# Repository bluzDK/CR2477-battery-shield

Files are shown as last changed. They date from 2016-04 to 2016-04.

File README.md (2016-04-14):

<p align="center" >
Bluz
</p>

Bluz CR2477 Battery Shield Hardware Files
==========
Bluz is a Development Kit (DK) that implements the Wiring language and talks to the [Particle](https://www.particle.io/) cloud through Bluetooth Low Energy. It can be accessed through a REST API and programmed from a Web IDE.

The CR2477 battery shield is intended to let bluz run off the biggest, baddest coin cell battery in the land.

This shield is not produced or sold, the files are provided here as a reference or so others can create the shield themselves. The PCB can be purchased from [OSH Park directly here](https://oshpark.com/shared_projects/7VCoguxF). The BOM has all the parts listed with links to DigiKey for easy purchase. 

These files have been made available online through a [Creative Commons Attribution-ShareAlike 3.0](http://creativecommons.org/licenses/by-sa/3.0/) license.

You are welcome to distribute, remix, and use these files for commercial purposes. If you do so, please attribute the original design to Bluz both on the website and on the physical packaging of the product or in the instruction manual. All derivative works must be published under the same or a similar license.

All items are subject to change over time as the product is designed, so make sure you are always looking at the latest information by pulling often.

##Sections
<b>BOM</b>: Current Bill of Materials for the battery shield.

<b>HW Design</b>: Schematics, board layouts, and other design files.

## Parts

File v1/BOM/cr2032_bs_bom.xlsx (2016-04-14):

Part(s) | Package | Value | Description | Qty | Manufacturer | Mfg. Part Number | DigiKey Page | Data Sheet | Notes
Q1 | SOT323 |  | P-Channel MOSFET for reverse polarity protection | 1 | On | NTS2101PT1G | purchase (http://www.digikey.com/product-detail/en/on-semiconductor/NTS2101PT1G/NTS2101PT1GOSCT-ND/687135) | data (http://www.onsemi.com/pub_link/Collateral/NTS2101P-D.PDF)
S1 | Thru |  | DPDT Power Switch | 1 | E-Switch | EG1270 | purchase (http://www.digikey.com/product-detail/en/e-switch/EG1270/EG1847-ND/6076) | data (https://www.e-switch.com/system/asset/product_line/data_sheet/119/EG.pdf)
S2 | SMD |  | Jumper for LED | 1 | Copal | CHS-01TA | purchase (http://www.digikey.com/product-detail/en/copal-electronics-inc/CHS-01TA/563-1003-1-ND/948404) | data (http://www.nidec-copal-electronics.com/e/catalog/switch/chs.pdf)
C1 | 0603 | 0.1uF | 0603 Package | 1 |  | GRM188R71C104KA01D | purchase (http://www.digikey.com/product-detail/en/murata-electronics-north-america/GRM188R71C104KA01D/490-1532-1-ND/587771) | data (http://search.murata.co.jp/Ceramy/image/img/A01X/partnumbering_e_01.pdf)
L1 | 0603 |  | White SMD LED | 1 |  | LW Q38G-Q1S1-3K6L-1 | purchase (http://www.digikey.com/product-detail/en/osram-opto-semiconductors-inc/LW%20Q38G-Q1OO-3K6L-1/475-2832-1-ND/2176370) | data (http://www.osram-os.com/Graphics/XPic6/00086183_0.pdf)
R1 | 0603 | 1k Ohm | 1k Ohm | 1 |  | CRCW06031K00FKEA | purchase (http://www.digikey.com/product-detail/en/vishay-dale/CRCW06031K00FKEA/541-1.00KHCT-ND/1179809) | data (http://www.vishay.com/docs/20035/dcrcwe3.pdf)
BAT1 | SMD | 24mm | Battery holder for CR2477 | 1 | Keystone | 3039 | purchase (http://www.digikey.com/product-detail/en/keystone-electronics/3039/36-3039-ND/3884009) | data (http://keyelco.com/userAssets/file/M65p9.pdf)
JP2, JP3 | Thru |  | 0.1" 12-pin female header | 2 |  | PPTC121LFBN-RC | purchase (http://www.digikey.com/product-detail/en/sullins-connector-solutions/PPTC121LFBN-RC/S6100-ND/807231) | data (http://www.sullinscorp.com/drawings/78_P(N)PxCxxxLFBN-RC,_10492-H.pdf)

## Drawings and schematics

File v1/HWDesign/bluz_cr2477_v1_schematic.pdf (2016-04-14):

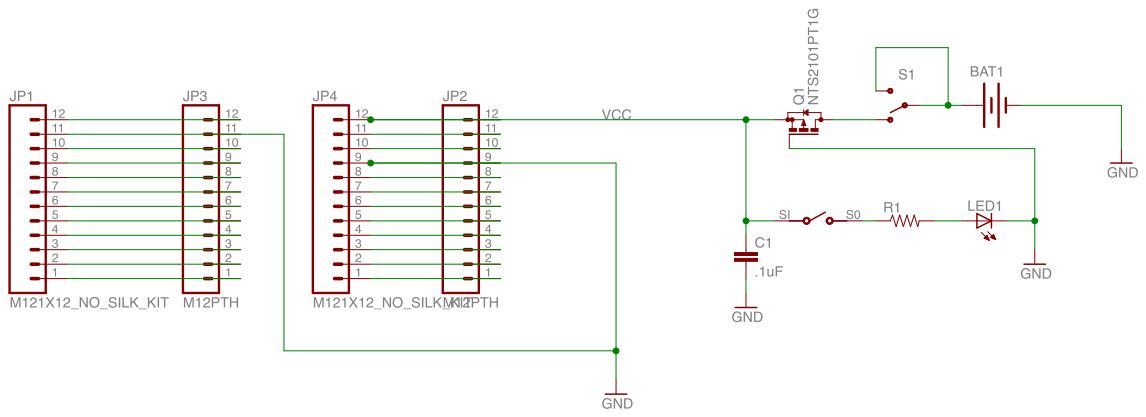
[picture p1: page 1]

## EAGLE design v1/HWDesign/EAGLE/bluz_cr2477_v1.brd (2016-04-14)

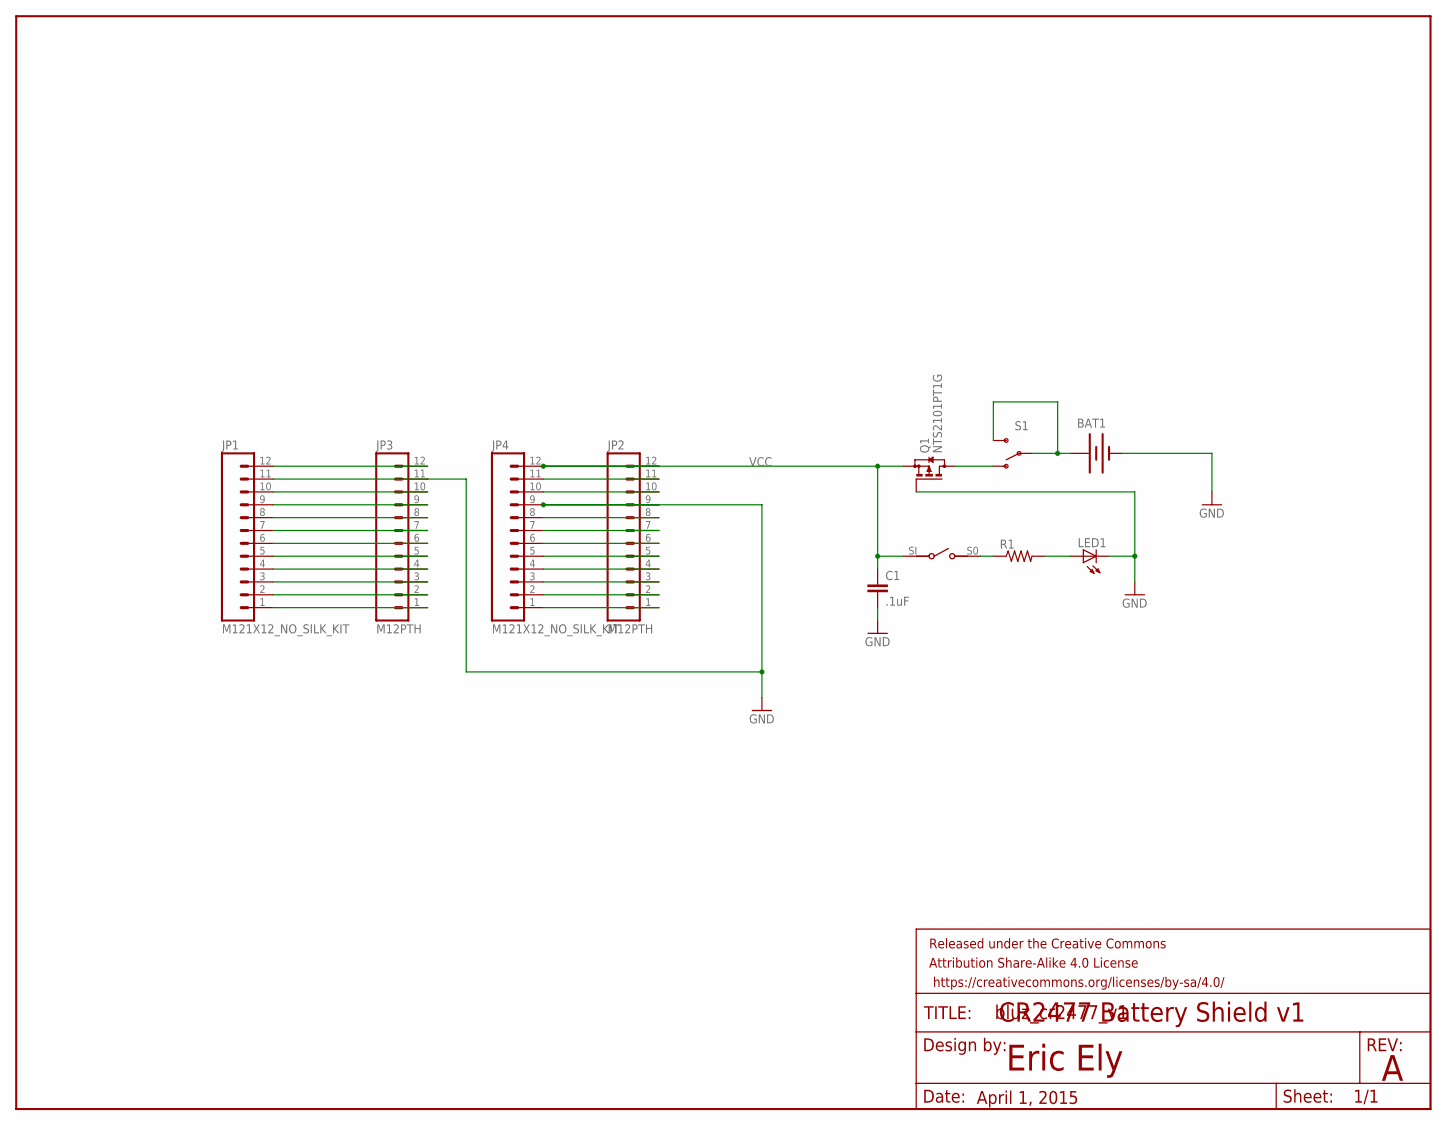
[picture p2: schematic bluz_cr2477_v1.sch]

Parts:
BAT1: BATTERY245PTH; BATTCON_245MM_PTH
C1: .1uF; 0603-CAP
FRAME1: FRAME-LETTER; CREATIVE_COMMONS
JP1, JP4: M121X12_NO_SILK_KIT; 1X12_NO_SILK_KIT
JP2, JP3: M12PTH; 1X12
LED1: LEDCHIPLED_0603; CHIPLED_0603
Q1: NTS2101PT1G; SOT323
R1: RESISTOR0603-RES; 0603-RES
S1: SWITCH-SPDTKIT; SWITCH-SPDT_KIT
S2: CHS-01TASMD; CHS-01TA

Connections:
GND: BAT1.2 (-), C1.2, JP1.11, JP2.9, JP3.11, JP4.9, LED1.C, Q1.1 (G)
unnamed: BAT1.3 (+), S1.2, S1.3 (S)
unnamed: JP1.1, JP3.1
unnamed: LED1.A, R1.2
unnamed: R1.1, S2.S0 (SO)
unnamed: Q1.3 (D), S1.1 (O)
unnamed: JP1.2, JP3.2
unnamed: JP1.3, JP3.3
unnamed: JP1.4, JP3.4
unnamed: JP1.5, JP3.5
unnamed: JP1.6, JP3.6
unnamed: JP1.7, JP3.7
unnamed: JP1.8, JP3.8
unnamed: JP1.9, JP3.9
unnamed: JP1.10, JP3.10
unnamed: JP1.12, JP3.12
unnamed: JP2.1, JP4.1
unnamed: JP2.2, JP4.2
unnamed: JP2.3, JP4.3
unnamed: JP2.4, JP4.4
unnamed: JP2.5, JP4.5
unnamed: JP2.6, JP4.6
unnamed: JP2.7, JP4.7
unnamed: JP2.8, JP4.8
unnamed: JP2.10, JP4.10
unnamed: JP2.11, JP4.11
VCC: C1.1, JP2.12, JP4.12, Q1.2 (S), S2.SI (S!)

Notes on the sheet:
Eric Ely
April 1, 2015
CR2477 Battery Shield v1

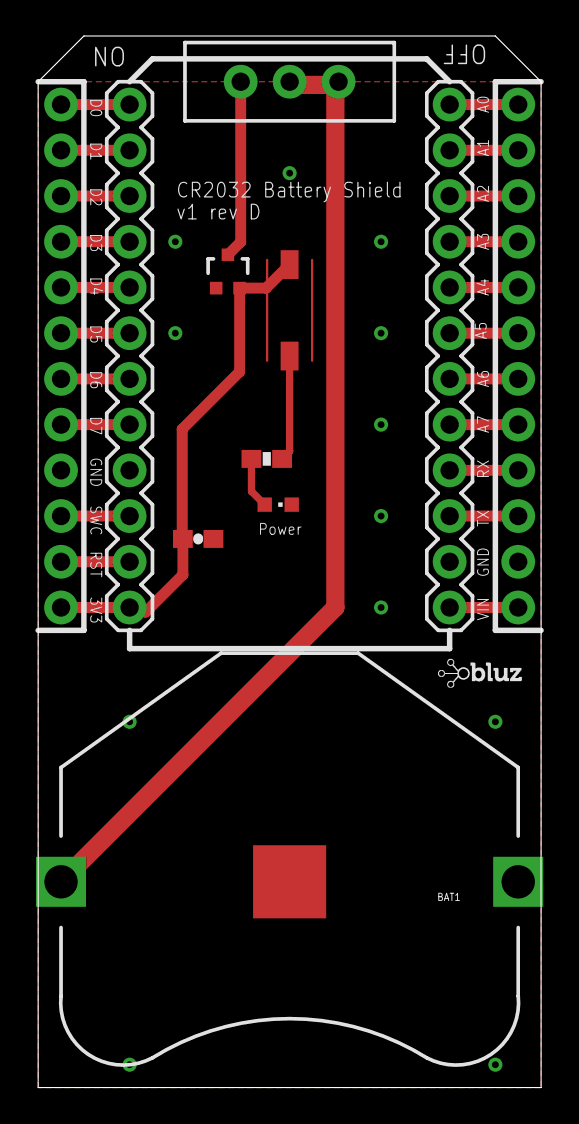
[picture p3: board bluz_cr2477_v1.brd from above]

Board: 2 copper layers, 27.9 x 58.4 mm, 13 parts (0 on the bottom side), 27 nets.

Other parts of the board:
U$1: BLUZE_LOGO_LOW_RES

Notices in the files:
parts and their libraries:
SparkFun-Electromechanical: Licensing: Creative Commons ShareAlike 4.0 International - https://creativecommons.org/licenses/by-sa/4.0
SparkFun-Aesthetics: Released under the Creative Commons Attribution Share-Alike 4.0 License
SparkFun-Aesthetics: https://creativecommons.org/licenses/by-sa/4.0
